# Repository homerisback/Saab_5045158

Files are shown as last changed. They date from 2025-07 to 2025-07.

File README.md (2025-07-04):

# Saab 5045158
Fan regulator mainboard/PCB to replace *SAAB 9-3 1998-2003* faulty regulator at reasonnable costs. #36 on diagram below

Due to high heating functioning tempreature, main MOSFET on board ends in failing. Board/soldering pads may be damaged as well as components.

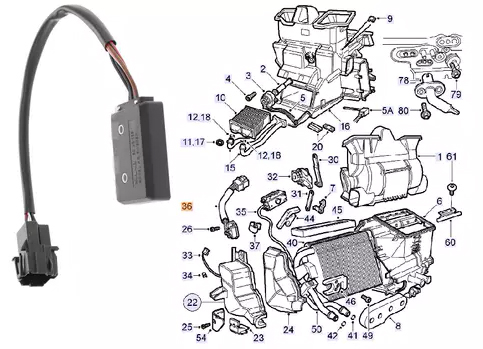
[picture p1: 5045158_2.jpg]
SAAB ACC diagram


This is made to replace PCB and its components, you need to take back from original SAAB part #5045158 :
  - wiring and connector
  - housing and screws
  - vertical plate on PCB<br>
  
## Build and use this at your own risks.<br>High intensity involved that may lead to fire if not properly build<br>**Check twice** there are no shortcuts or badly soldered components.<br>

Inital intention was to replace faulty part but after a close magnified look that showed the damage, I ended to make a complete 1:1 copy of original board layout under Eagle CAD.<br>
Schematic & board design files are available up here.

Ordering PCB is doable at [OSHPark](https://oshpark.com/projects/qXP4BEkH/view_design) (**note that they sell boards by sets of 3 minimum**)<br>

Here is a BOM to order parts - *I ordered at Mouser's, that's why I left their ref in table below*  
(***note that some parts are SMD - be sure to have ability and tools to solder them***)

| N° Mouser : | N° de fab. : | Desc. : | Client ref. | Qty |
|---|---|---|---|-----|
| 844-IRFP054PBF | IRFP054PBF | MOSFET TO247 N CHANNEL 60V | VT1 | 1 |
| 512-BC547B | BC547B | BJT NPN Epitaxial Silicon Transistor | VT2 | 1 |
| 603-MF0204FTE52-3K16 | MF0204FTE52-3K16 | Through hole 3.16Kohms 1% 1/8watt | R13 | 1 |
| 594-5063JD10K50F | MBA02040C1052FC100 | Through hole 10.5Kohms 1% 1/8watt body size | R11 | 1 |
| 71-CMF5078K700FHEB | CMF5078K700FHEB | Through hole 1/4watt 78.7Kohms 1% | R14 | 1 |
| 71-MBA02040C2200FCT0 | MBA02040C2200FCT00 | Through hole 1/4watt 220ohm 1% 50ppm | R8-9 | 2 |
| 594-5063JD6K200FT | MBA02040C6201FRP00 | Through hole 6.2Kohms 1% 1/8watt body size | R3,R7 | 2 |
| 594-5063JD2K200F5 | MBA02040C2201FCT00 | Through hole 2.2Kohms 1% 1/8watt body size | R1-2 | 2 |
| 594-5063JD1K000FT | MBA02040C1001FRP00 | Through hole 1Kohms 1% 1/8watt body size | R15 | 1 |
| 594-5063JD10K1%TR | MBA02040C1002FRP00 | Through hole 10Kohms 1% 1/8watt body size | R4,R12 | 2 |
| 594-5063JD100K0F5 | MBA02040C1003FCT00 | Through hole 100Kohms 1% 1/8watt body size | R5 | 1 |
| 595-LM2904BTQDRQ1 | LM2904BTQDRQ1 | Amplis-Op Automotive-grade du al 36-V 1.2-MHz op | U1 | 1 |
| 594-5063JD18K70F | MBA02040C1872FC100 | Through hole 18.7Kohms 1% 1/8watt body size | R6 | 1 |
| 603-AC0805JNPO9BN181 | AC0805JRNPO9BN181  | MLCC - CMS 50 V 180pF C0G 0805 5% | C4, C6-11 | 7 |
| 810-FA14C0G2A103JNU6 | FA14C0G2A103JNU06  | Through hole MLCC 100V 0.01uF C0G 5% RAD LS:2.5mm | C1 | 1 |
| 810-FA28X8R1H104KRU6 | FA28X8R1H104KRU06  | Through hole MLCC 50V 0.1uF X8R 10% RAD LS:5mm | C2-3,C5 | 3 |
| 621-1N4007 | 1N4007-T | Diode Vr/1000V Io/1A T/R | D1 | 1 |
<br>
<br>
<br>

# Work done !
<details>
  
  <summary>Have a look at the brand new board</summary>
  
Here's the new board soldered and ready to mount in car and enjoy a working fan  

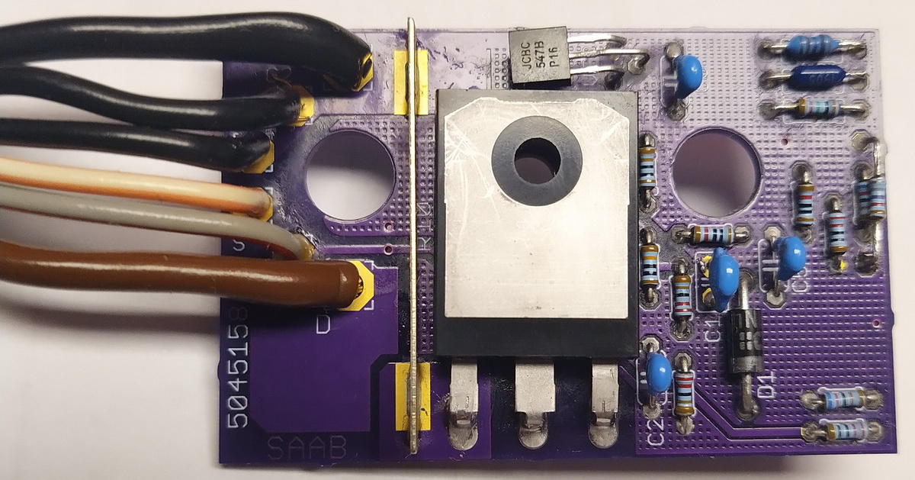
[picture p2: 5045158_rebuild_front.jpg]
SAAB rebuild front


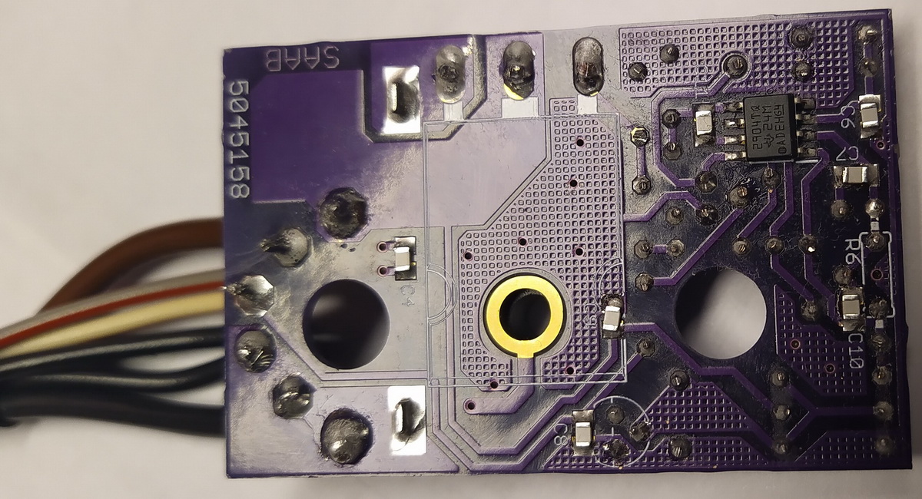
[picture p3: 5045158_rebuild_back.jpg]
SAAB rebuild back

</details>

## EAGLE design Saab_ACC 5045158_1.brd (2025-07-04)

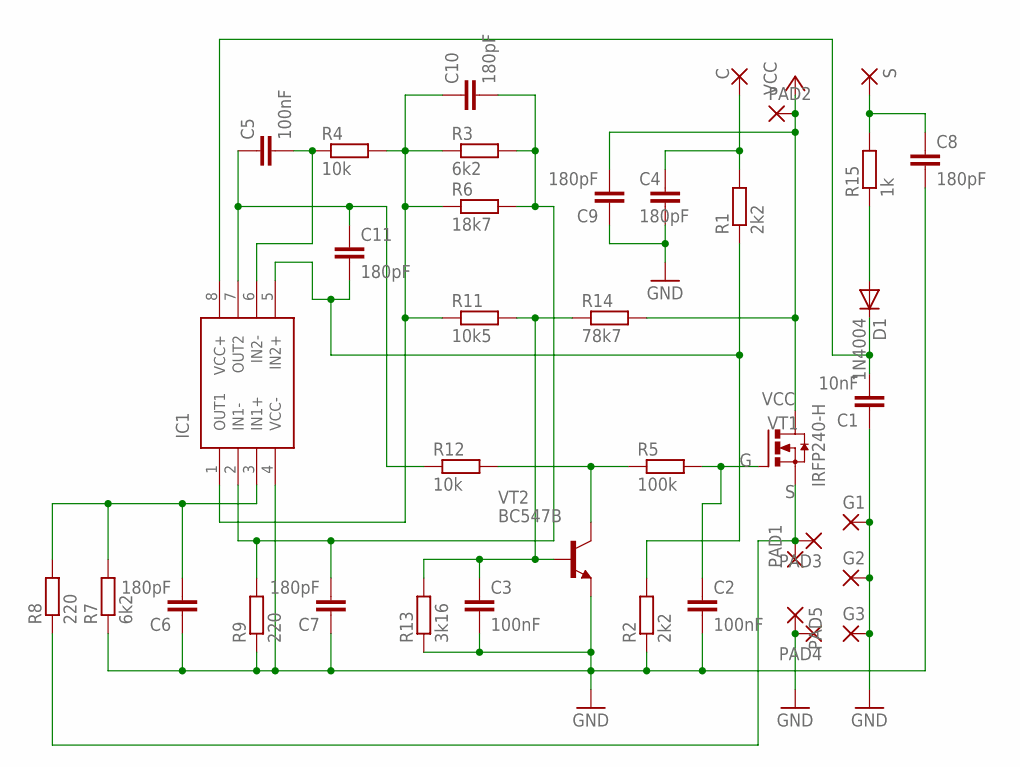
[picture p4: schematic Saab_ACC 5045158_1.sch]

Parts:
C: 3,17/1,3
C1: 10nF; C2.5-2
C2, C3, C5: 100nF; C050-024X044
C4, C6, C7, C8, C9, C10, C11: 180pF; C0805K
D1: 1N4004; DO41-10
G1: 3,81/1,4
G2, G3: 3,17/1,3
IC1: LM2904YDT; SOIC127P600X175-8N
PAD1, PAD3, PAD4, PAD5: SMD5; SMD2,54-5,08
PAD2: 3,81/1,4
R1, R2: 2k2; 0204/5
R3, R7: 6k2; 0204/5
R4, R12: 10k; 0204/5
R5: 100k; 0204/5
R6: 18k7; 0207/10
R8, R9: 220; 0204/5
R11: 10k5; 0204/7
R13: 3k16; 0204/7
R14: 78k7; 0204/7
R15: 1k; 0204/5
S: 3,17/1,3
VT1: IRFP240-H; TO247BH
VT2: BC547B; TO92

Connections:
C: C.1, C4.1, R1.2
G: C2.1, R5.2, VT1.G
GND: C1.1, C2.2, C3.2, C4.2, C6.1, C7.1, C8.2, C9.1, G1.1, G2.1, G3.1, IC1.4 (VCC-), PAD4.1, PAD5.1, R2.1, R7.1, R9.1, R13.1, VT2.1 (E)
unnamed: R5.1, R12.2, VT2.3 (C)
unnamed: C5.1, C11.1, IC1.7 (OUT2), R12.1
unnamed: C5.2, IC1.6 (IN2-), R4.1
unnamed: C10.1, IC1.1 (OUT1), R3.1, R4.2, R6.1, R11.1
unnamed: C7.2, C10.2, IC1.2 (IN1-), R3.2, R6.2, R9.2
unnamed: C3.1, R11.2, R13.2, R14.1, VT2.2 (B)
unnamed: C11.2, IC1.5 (IN2+), R1.1, R2.2
unnamed: C6.2, IC1.3 (IN1+), R7.2, R8.2
unnamed: C8.1, R15.2, S.1
unnamed: D1.A, R15.1
unnamed: C1.2, D1.C, IC1.8 (VCC+)
S: PAD1.1, PAD3.1, R8.1, VT1.S
VCC: C9.2, PAD2.1, R14.2, VT1.D

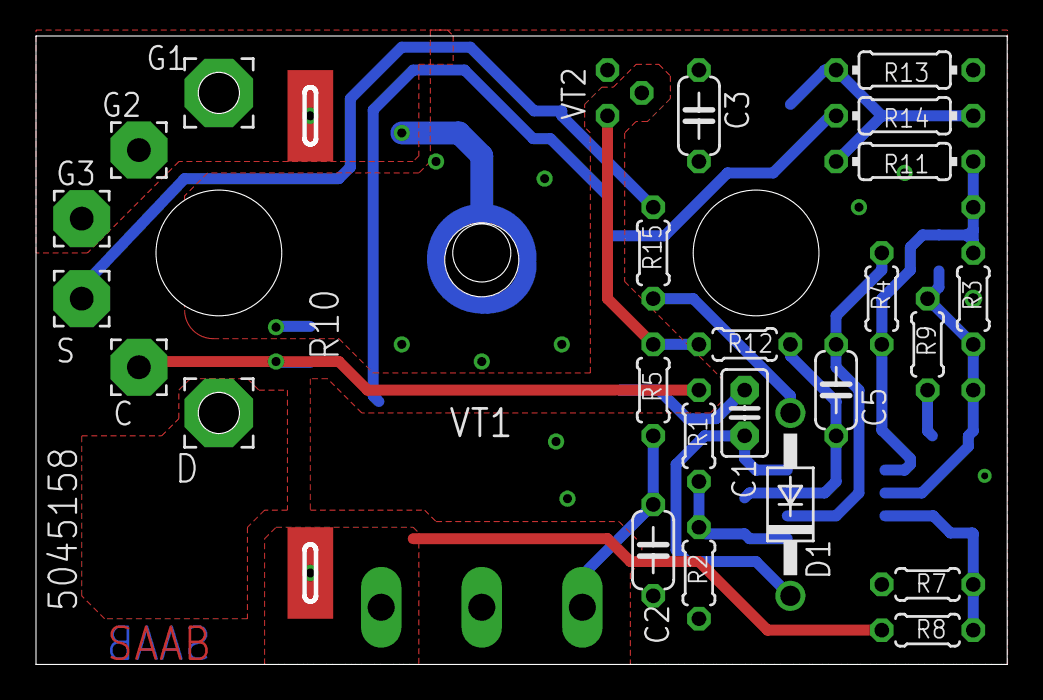
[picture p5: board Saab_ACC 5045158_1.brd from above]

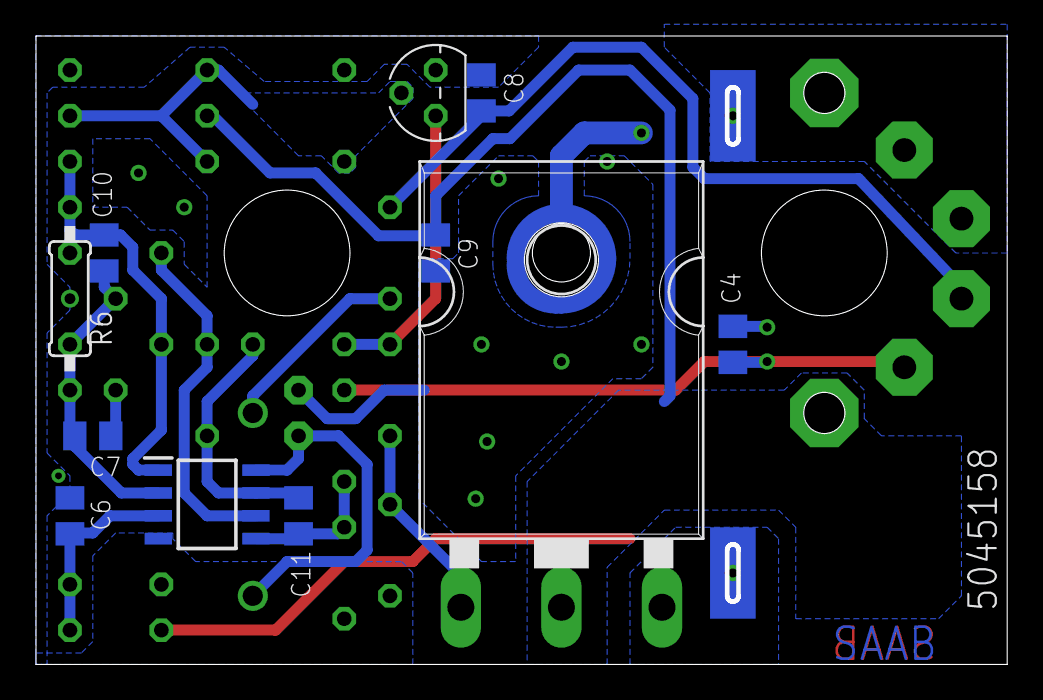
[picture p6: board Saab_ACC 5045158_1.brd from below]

Board: 2 copper layers, 54.0 x 34.9 mm, 39 parts (13 on the bottom side), 16 nets.
